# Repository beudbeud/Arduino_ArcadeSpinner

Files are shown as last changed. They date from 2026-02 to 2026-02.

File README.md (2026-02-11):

# Arduino Arcade Spinner

Ce projet est une recréation moderne des spinners utilisés dans les bornes d'arcade, principalement pour les casse-briques comme Arkanoid.

L'objectif est d'offrir une sensation proche de l'équipement d'origine en utilisant des composants faciles à obtenir.

Spinner
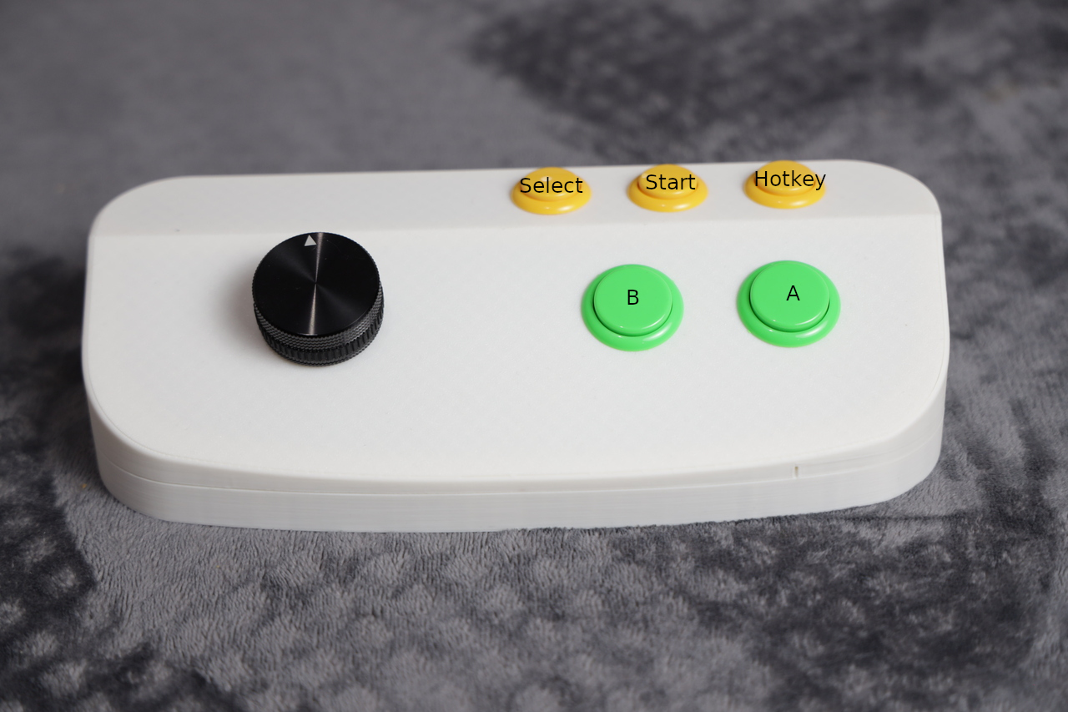
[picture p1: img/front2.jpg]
Spinner

Spinner

## Utilisation

Par défaut, l'appareil fonctionne comme un contrôleur à 5 boutons avec spinner, émulant une souris USB.

**Fonctionnalités :**
- Spinner haute précision (600 PPR par défaut)
- 5 boutons mappés sur les boutons de souris (gauche, droit, milieu, latéral, extra)
- 5 profiles de sensibilité ajustable via raccourcie
- Compatibilité universelle (Windows, Linux, MacOS, RetroPie, MiSTer, etc.)

### Changement de profile

Il y a 5 profiles:

 * Profile 0: Omega Race   - 64 PPR (Sega standard)
 * Profile 1: Tempest      - 72 PPR (Atari vector standard)
 * Profile 2: Tron/DoT     - 128 PPR
 * Profile 3: Blasteroids  - 288 PPR
 * Profile 4: Arkanoid     - 486 PPR (très sensible)

Par défaut au démarrage le spinner est configuré avec le profile 4. En jeux il est possible de changer le profile via le raccourci `Hotkey` + `B` pour diminer la sensibilité ou `Hotkey` + `A` pour augementer.

## Construire le vôtre

### Liste des composants

| Composant | Modèle recommandé | Quantité |
|---|---|---|
| Encodeur rotatif | C38S6G5-600B-G24N (600 PPR) | 1 |
| Microcontrôleur | Arduino | 1 |
| Boutons 24mm | Standard arcade | 3 |
| Boutons 30mm | Standard arcade | 2 |
| Boîtier | [Impression 3D](https://github.com/beudbeud/Arduino_ArcadeSpinner/tree/main/3D%20Files) ou boîte quelconque | 1 |
| Câbles | Dupont ou fils de connexion | - |

**Où acheter :**
- Encodeur rotatif : [AliExpress](https://fr.aliexpress.com/item/1005004359395872.html), Amazon (chercher "600PPR rotary encoder")
- Arduino Pro Micro : [AliExpress](https://fr.aliexpress.com/item/1005006734882677.html), [Amazon](https://www.amazon.fr/d%C3%A9veloppement-Binghe-Microcontr%C3%B4leurs-Interfaces-Compatible/dp/B0D69JLJ97), boutiques électronique
- Boutons arcade : [Boutiques spécialisées arcade](https://www.smallcab.net/boutons-c-30_35.html) ou AliExpress

### Schéma de câblage Arduino

Pinout Arduino

Les boutons doivent être connectés à la masse (GND). Vous pouvez créer une chaîne pour utiliser un GND commun pour tous vos boutons. Utilisez de la soudure ou des connecteurs de fils.

**⚠️ Important :** Faites le pont sur le pad J1 pour envoyer +5V à l'encodeur au lieu de 3.3V

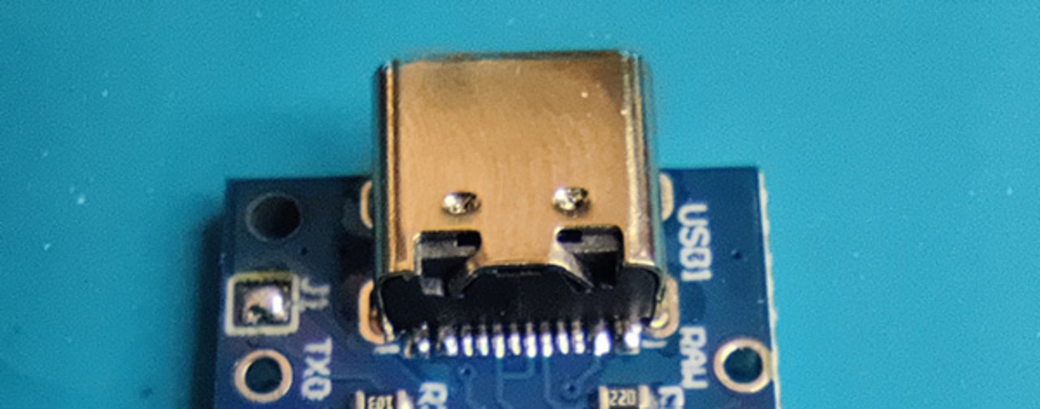
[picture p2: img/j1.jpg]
Pinout J1


#### Connexions détaillées

**Encodeur rotatif :**
```
Encodeur    →    Arduino Pro Micro
────────────────────────────────────
GND (fil noir)  →    GND
VCC (fil rouge) →    VCC (bridger J1 pour 5V)
A (fil blanc)   →    Pin 2 (GP_2)
B (fil vert)    →    Pin 3 (GP_3)
```
Pinout Rotary

**Boutons :**
```
Fonction          →    Pin Arduino    
─────────────────────────────────────
Button0 (B)      →    Pin 5 (GP_5)   
Button1 (A)      →    Pin 4 (GP_4)   
Button4 (Select) →    Pin 6 (GP_6)   
Button2 (Start)  →    Pin 14 (GP_14) 
Button3 (Hotkey) →    Pin 15 (GP_15) 
```
**Schéma de connexion des boutons :**
```
Relier toutes les masses → GND
```
Pinout Rotary

## Flasher votre Arduino

### Étape 1 : Installer Arduino IDE

1. Télécharger [Arduino IDE 2.x](https://www.arduino.cc/en/software)
2. Installer l'IDE sur votre ordinateur
3. Lancer Arduino IDE

### Étape 2 : Installer la bibliothèque HID-Project

1. Aller dans **Sketch** → **Include Library** → **Manage Libraries**
2. Rechercher "HID-Project"
3. Installer la bibliothèque

### Étape 3 : Configurer la carte

1. Connecter votre **Arduino Pro Micro** à l'ordinateur via USB
2. Dans Arduino IDE :
   - **Outils** → **Type de carte** → Sélectionner **Arduino Leonardo**
   - **Outils** → **Port** → Sélectionner le port COM correct

**Note :** L'Arduino Pro Micro utilise le même bootloader que le Leonardo.

### Étape 4 : Téléverser le code

1. Ouvrir le fichier `Arduino_ArcadeSpinner.ino`
2. Ajuster les paramètres de sensibilité si nécessaire (voir section Configuration)
3. Cliquer sur **Téléverser** (flèche →)
4. Attendre la compilation et le téléversement

## Options de personnalisation du code

Tous les paramètres ajustables se trouvent en haut du fichier `Arduino_ArcadeSpinner.ino` :

| Paramètre | Défaut | Description |
|---|---|---|
| `ENCODER_PPR` | 600 | PPR de votre encodeur (300, 360, 400, 600...) |
| `GAME_PPR[]` | 5 profils | Tableau des profils de sensibilité (modifiable/extensible) |
| `DEFAULT_PROFILE` | 4 | Profil au démarrage (index du tableau, 0 = premier) |
| `SENSITIVITY_MULTIPLIER` | 5 | Vitesse globale : 5 = précis, 10 = normal, 20 = rapide |
| `SCROLL_SENSITIVITY` | 400 | Sensibilité molette (↑ = moins sensible) |
| `RESPONSE_DELAY` | 1 | Délai en ms (1-2 recommandé) |
| `DEAD_ZONE` | 1 | Filtrage vibrations : 0 = off, 1-3 = recommandé |
| `LED_BLINK_TIME` | 80 | Durée clignotement LED (ms) |

### Profils de jeux (valeurs PPR arcade)

```
64  → Omega Race, Tac/Scan (Sega)    288 → Blasteroids
72  → Tempest, Super Sprint (Atari)  486 → Arkanoid, Puchi Carat
128 → Tron, Disks of Tron            144 → 720 Degrees
```

Pour ajouter un profil, ajoutez simplement une valeur au tableau `GAME_PPR[]`.

## Licence

Ce projet est sous licence GNU General Public License v3.0.

Basé sur les travaux de :
- Adrien Beudin ([beudbeud](https://github.com/beudbeud))
- Benoit BOUNAR (Bounitos) pour le boitier
- Alexey Melnikov ([MiSTer-devel](https://github.com/MiSTer-devel))
- Mikael Norrgård (mick@daemonbite.com)
- [willoucom](https://github.com/willoucom/Arduino_ArcadeSpinner)

## Contributions

Les contributions sont les bienvenues ! N'hésitez pas à :
- Ouvrir des issues pour signaler des bugs
- Proposer des améliorations via pull requests
- Partager vos builds et configurations

## Ressources supplémentaires

- [Documentation HID-Project](https://github.com/NicoHood/HID)
- [Arduino Pro Micro Guide](https://learn.sparkfun.com/tutorials/pro-micro--fio-v3-hookup-guide)
- [MAME Configuration Guide](https://docs.mamedev.org/)
- [Forum Arcade Controls](http://forum.arcadecontrols.com/)

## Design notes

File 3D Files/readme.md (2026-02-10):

# Arcade Spinner Case - 3D Model

[Français](#français) | [English](#english)

---

## 🇫🇷 Français

Ce dépôt contient les fichiers de conception numérique pour la coque du projet **Arduino Arcade Spinner**.

### 🔗 Projet Source
Ce modèle est optimisé pour le projet de spinner DIY :
👉 [Arduino Arcade Spinner sur GitHub](https://github.com/beudbeud/Arduino_ArcadeSpinner/tree/main)

### 👤 Auteur
- **Benoit BOUNAR** (Bounitos)

### 📁 Liste des fichiers (Nomenclature)
* **Panel.stl** : Panel principal.
* **Panel_Top_With_Logo.stl** : Panel supérieur avec emplacement logo.
* **Panel_Top_No_Logo.stl** : Panel supérieur (vierge).
* **Logo_Recalbox.stl** : Logo Recalbox à insérer.
* **Base.stl** : Partie inférieure (socle).
* **Arduino_Mount.stl** : Support de fixation interne pour l'Arduino.

### 📜 Conditions de Licence
Ce modèle numérique est mis à disposition sous licence **Creative Commons Attribution - Pas d'Utilisation Commerciale - Partage dans les Mêmes Conditions 4.0 International (CC BY-NC-SA 4.0)**.

**En utilisant ces fichiers, vous acceptez les clauses suivantes :**

* **Exploitation Non-Commerciale :** Toute exploitation commerciale de ce modèle, des fichiers sources ou des objets physiques issus de l'impression 3D est **strictement interdite**. Cela inclut la vente de kits, de coques pré-imprimées ou l'inclusion du design dans un produit payant.
* **Œuvres Dérivées :** La création d'œuvres dérivées (modifications, adaptations) est autorisée, à condition qu'elles soient distribuées sous une licence identique.
* **Obligation d'Attribution :** Toute redistribution ou exposition du modèle doit impérativement mentionner l'auteur original : **Benoit BOUNAR**, avec un lien vers le projet GitHub source.
* **Exclusion de Garantie :** Le modèle est fourni "en l'état", sans garantie de compatibilité matérielle ou de succès d'impression. L'auteur ne peut être tenu responsable des dommages liés à l'utilisation du modèle.

---

## 🇺🇸 English

This repository contains the digital design files for the **Arduino Arcade Spinner** housing.

### 🔗 Source Project
This model is designed for the following DIY Spinner project:
👉 [Arduino Arcade Spinner on GitHub](https://github.com/beudbeud/Arduino_ArcadeSpinner/tree/main)

### 👤 Author
- **Benoit BOUNAR** (Bounitos)

### 📁 File List (Nomenclature)
* **Panel.stl** : Main control panel.
* **Panel_Top_With_Logo.stl** : Upper panel with logo cutout.
* **Panel_Top_No_Logo.stl** : Upper panel (blank version).
* **Logo_Recalbox.stl** : Recalbox logo insert.
* **Base.stl** : Bottom base.
* **Arduino_Mount.stl** : Internal mounting bracket for the Arduino.

### 📜 Licensing Terms
This digital model is released under the **Creative Commons Attribution-NonCommercial-ShareAlike 4.0 International (CC BY-NC-SA 4.0)** license.

**By downloading or using these files, you agree to the following terms:**

* **Non-Commercial Restriction:** Any commercial exploitation of this model, its source files, or physical objects derived from 3D printing is **strictly prohibited**. This includes the sale of kits, pre-printed cases, or the inclusion of this design in a paid product.
* **Derivative Works:** You are permitted to remix or transform the material, provided that any derivative works are distributed under the same license as the original.
* **Mandatory Attribution:** Any redistribution or display of the model must include clear credit to the original author: **Benoit BOUNAR**, along with a link to the source GitHub repository.
* **Disclaimer of Warranty:** The model is provided "as is", without warranty of any kind. The author shall not be held liable for any damages resulting from the use or printing of this model.

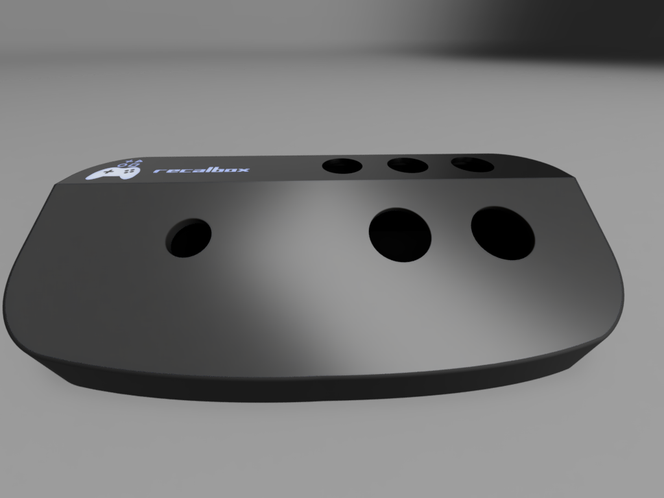
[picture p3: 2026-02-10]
3D Files/_Complete Case.png

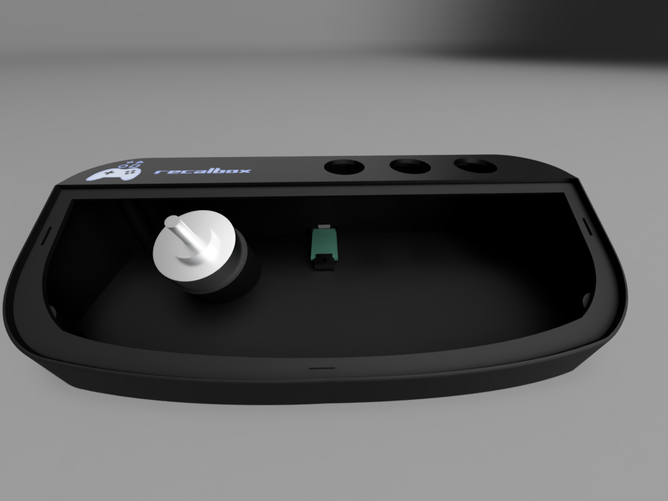
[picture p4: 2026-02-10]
3D Files/_Base + top case + Panel top.png

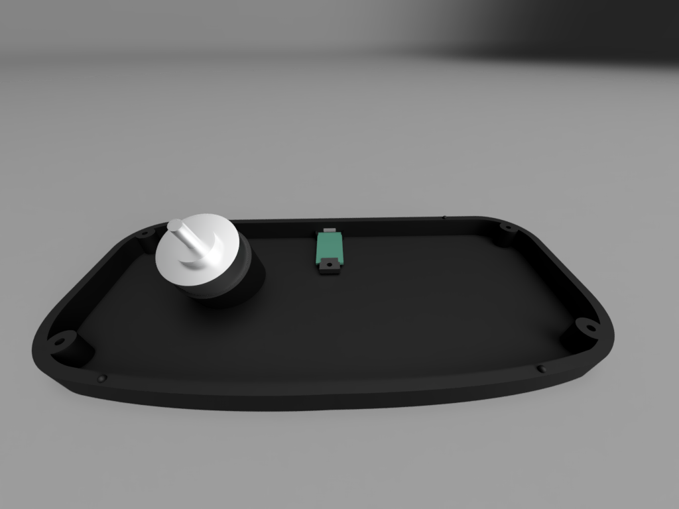
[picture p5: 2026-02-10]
3D Files/_base.png

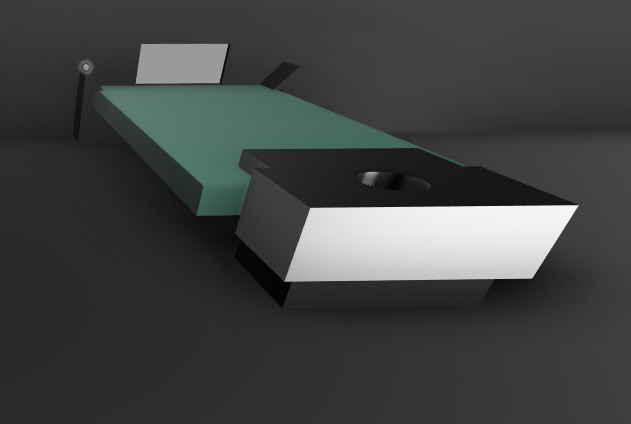
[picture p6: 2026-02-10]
3D Files/_Arduino Holder.png

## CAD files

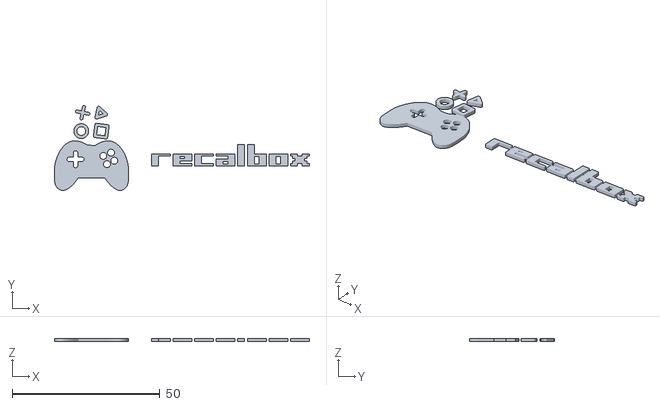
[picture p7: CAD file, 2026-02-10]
3D Files/STL files/Logo recalbox.stl
86.2 x 28.8 x 1.10

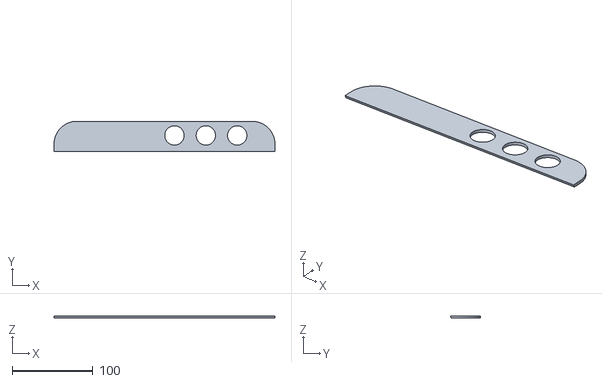
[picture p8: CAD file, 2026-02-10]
3D Files/STL files/Panel Top - without logo.stl
274.5 x 37.8 x 3.00

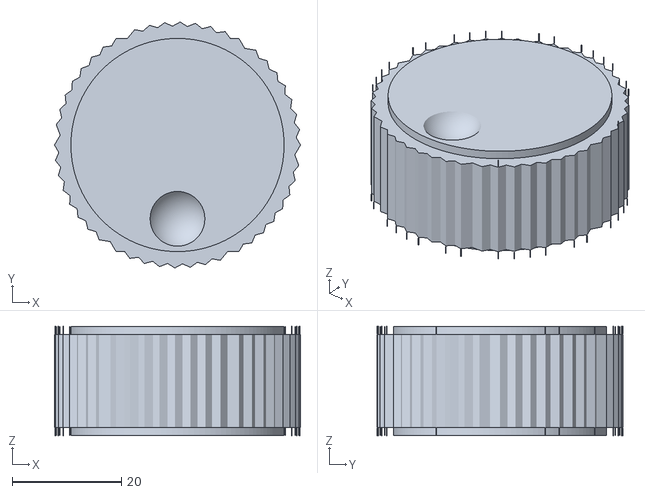
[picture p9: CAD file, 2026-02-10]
3D Files/STL files/Knob - Knob D-shape - D 42mm - H 20mm 3.stl
45.0 x 45.0 x 20.0

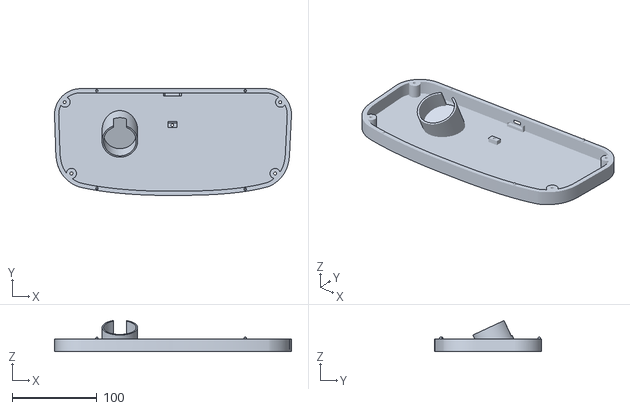
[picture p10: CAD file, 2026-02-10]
3D Files/STL files/Base.stl
279.3 x 125.8 x 36.5

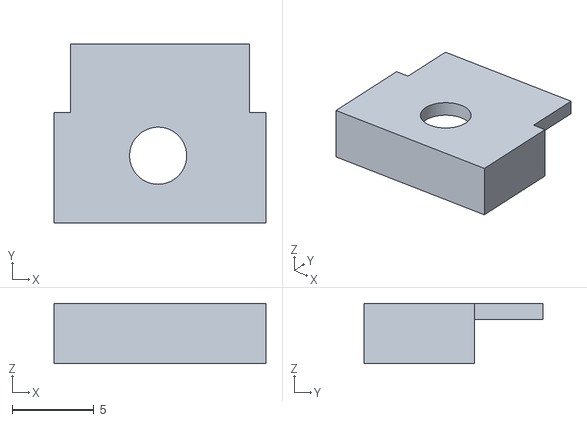
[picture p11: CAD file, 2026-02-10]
3D Files/STL files/Arduino Holder.stl
13.0 x 11.0 x 3.70

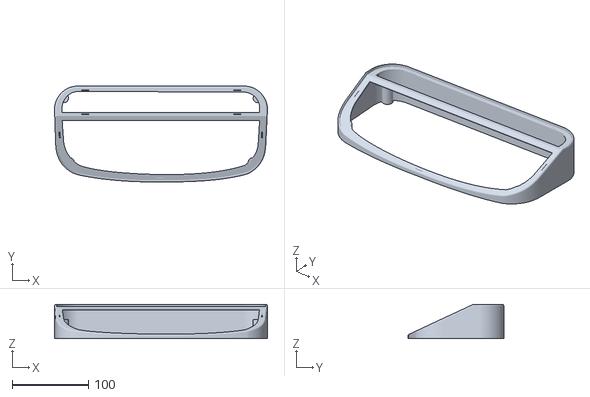
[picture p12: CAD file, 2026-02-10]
3D Files/STL files/Top_case.stl
279.3 x 125.8 x 45.0

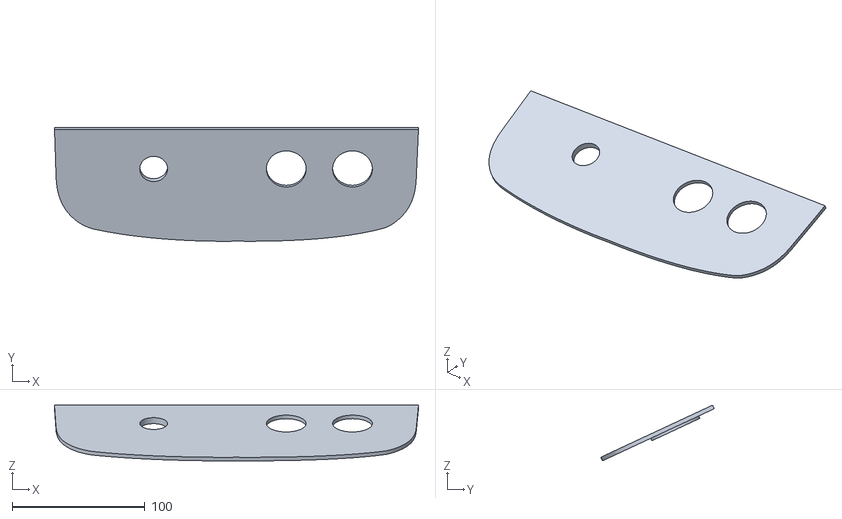
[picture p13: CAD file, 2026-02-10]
3D Files/STL files/Panel.stl
274.5 x 85.7 x 42.1

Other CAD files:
3D Files/STL files/Panel top - with logo.stl

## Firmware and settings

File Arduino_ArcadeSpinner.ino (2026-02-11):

/*
 *  Arduino USB Arcade Spinner
 *  (C) Adrien Beudin [https://github.com/beudbeud]
 *
 *  Based on project by Alexey Melnikov [https://github.com/MiSTer-devel/Retro-Controllers-USB-MiSTer/blob/master/PaddleTwoControllersUSB/PaddleTwoControllersUSB.ino]
 *  Based on project by Mikael Norrgård <mick@daemonbite.com>
 *  Based on project [https://github.com/willoucom/Arduino_ArcadeSpinner]
 *
 *  GNU GENERAL PUBLIC LICENSE
 *  Version 3, 29 June 2007
 *
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
 */

///////////////// Customizable settings /////////////////////////

// Your encoder's PPR (Pulses Per Revolution)
// Common values: 300, 360, 400, 600
// Quadrature encoding multiplies this by 4 (600 PPR = 2400 counts)
#define ENCODER_PPR 600
#define ENCODER_COUNTS (ENCODER_PPR * 4)  // 2400 for 600 PPR encoder

/*
 * Game Profiles - Based on original arcade hardware PPR
 *
 * Add, remove or modify profiles as needed!
 * Just update GAME_PPR array and NUM_PROFILES will auto-calculate.
 *
 * Common arcade game PPR values:
 *   64  - Omega Race, Tac/Scan, Zektor, Star Trek (Sega standard)
 *   72  - Tempest, Super Sprint (Atari vector standard)
 *   128 - Tron, Disks of Tron
 *   144 - 720 Degrees
 *   288 - Blasteroids
 *   486 - Arkanoid, Puchi Carat (geared, very sensitive)
 *
 * Sensitivity = ENCODER_COUNTS / GAME_PPR
 * Lower PPR value = less sensitive, Higher PPR value = more sensitive
 */

// ============== CUSTOMIZE YOUR PROFILES HERE ==============
const uint16_t GAME_PPR[] = {
  64,   // Profile 0: Omega Race / Sega
  72,   // Profile 1: Tempest / Atari
  128,  // Profile 2: Tron
  288,  // Profile 3: Blasteroids
  486   // Profile 4: Arkanoid / Puchi Carat
  // Add more profiles here, e.g.:
  // 144,  // Profile 5: 720 Degrees
  // 100,  // Profile 6: Custom
};
// ==========================================================

// Default profile index (0 = first profile in GAME_PPR array)
#define DEFAULT_PROFILE 4

// Sensitivity multiplier (adjusts speed on top of PPR profile)
// 5 = slower/more precise (0.5x), 10 = normal (1.0x), 20 = faster (2.0x)
// Using integer to avoid float operations in main loop
#define SENSITIVITY_MULTIPLIER 5

// Scroll wheel sensitivity (fixed, higher = less sensitive)
#define SCROLL_SENSITIVITY 400

// Response delay in ms (lower = more responsive, 1-2ms recommended)
#define RESPONSE_DELAY 1

// Dead zone - ignores small movements (noise/vibration filtering)
// 0 = disabled, 1-3 = recommended for filtering micro-movements
#define DEAD_ZONE 1

// LED feedback duration in ms
#define LED_BLINK_TIME 80

////////////////////// Don't Touche after that //////////////////

// Encoder pins
#define PIN_A 2
#define PIN_B 3

// Button pins
#define BTN_B      5   // Left button
#define BTN_A      4   // Right button
#define BTN_START  14  // Start button
#define BTN_HOTKEY 15  // Hotkey button
#define BTN_SELECT 6   // Select button

// Pro Micro onboard LEDs
#define LED_RX 17  // RX LED pin

#define SENSITIVITY_DIVISOR 10

// Auto-calculate number of profiles from array size
#define NUM_PROFILES (sizeof(GAME_PPR) / sizeof(GAME_PPR[0]))

#include <HID-Project.h>

// Mouse button definitions
#define MOUSE_SIDE  (1 << 3)
#define MOUSE_EXTRA (1 << 4)

// Spinner state
volatile int16_t spinnerPos = 0;

// Current profile
uint8_t currentProfile = DEFAULT_PROFILE;
uint16_t currentPPR = GAME_PPR[DEFAULT_PROFILE];

// Calculate sensitivity from PPR (inline function for efficiency)
inline uint8_t getSensitivity(uint16_t ppr) {  return ENCODER_COUNTS / ppr;
}

// Clamp value to int8 range
inline int8_t clamp8(int16_t val) {
  if (val > 127) return 127;
  if (val < -127) return -127;
  return val;
}

// Blink LEDs to indicate current profile
// Blinks (profile + 1) times: Profile 0 = 1 blink, Profile 4 = 5 blinks
void blinkProfile(uint8_t profile) {
  for (uint8_t i = 0; i <= profile; i++) {
    // Turn ON both LEDs (active LOW)
    digitalWrite(LED_RX, LOW);
    TXLED1;
    delay(LED_BLINK_TIME);

    // Turn OFF both LEDs
    digitalWrite(LED_RX, HIGH);
    TXLED0;
    delay(LED_BLINK_TIME);
  }
}

// Encoder interrupt handler (optimized with direct port reading)
void encoderISR() {
  static uint8_t prev = 0;

  // Direct port reading - much faster than digitalRead()
  // PIN_A = 2 = PD1, PIN_B = 3 = PD0 on Pro Micro
  uint8_t portD = PIND;
  uint8_t a = (portD >> 1) & 1;  // PD1 (pin 2)
  uint8_t b = portD & 1;          // PD0 (pin 3)

  uint8_t curr = (b << 1) | (b ^ a);
  int8_t diff = (prev - curr) & 3;

  if (diff == 1) spinnerPos++;
  else if (diff == 3) spinnerPos--;

  prev = curr;
}

void setup() {
  // Encoder pins
  pinMode(PIN_A, INPUT_PULLUP);
  pinMode(PIN_B, INPUT_PULLUP);

  // Button pins
  pinMode(BTN_A, INPUT_PULLUP);
  pinMode(BTN_B, INPUT_PULLUP);
  pinMode(BTN_START, INPUT_PULLUP);
  pinMode(BTN_HOTKEY, INPUT_PULLUP);
  pinMode(BTN_SELECT, INPUT_PULLUP);

  // LED pins
  pinMode(LED_RX, OUTPUT);
  digitalWrite(LED_RX, HIGH);  // OFF (active LOW)
  TXLED0;  // OFF

  // Attach encoder interrupts
  attachInterrupt(digitalPinToInterrupt(PIN_A), encoderISR, CHANGE);
  attachInterrupt(digitalPinToInterrupt(PIN_B), encoderISR, CHANGE);

  // Blink current profile on startup
  delay(500);
  blinkProfile(currentProfile);
}

void loop() {
  static bool prevBtnA = false;
  static bool prevBtnB = false;
  static int16_t prevMousePos = 0;
  static int16_t prevScrollPos = 0;

  // Read buttons
  bool hotkey = !digitalRead(BTN_HOTKEY);
  bool btnA = !digitalRead(BTN_A);
  bool btnB = !digitalRead(BTN_B);

  // Profile switching (Hotkey + A/B)
  // Hotkey + A = next profile (more sensitive)
  // Hotkey + B = previous profile (less sensitive)
  bool profileChanged = false;

  if (hotkey) {
    if (btnA && !prevBtnA && currentProfile < NUM_PROFILES - 1) {
      currentProfile++;
      currentPPR = GAME_PPR[currentProfile];
      profileChanged = true;
    }
    if (btnB && !prevBtnB && currentProfile > 0) {
      currentProfile--;
      currentPPR = GAME_PPR[currentProfile];
      profileChanged = true;
    }
  }
  prevBtnA = btnA;
  prevBtnB = btnB;

  const uint8_t buttons[] = {BTN_B, BTN_A, BTN_SELECT, BTN_START, BTN_HOTKEY};
  const uint8_t mouseButtons[] = {MOUSE_LEFT, MOUSE_RIGHT, MOUSE_SIDE, MOUSE_EXTRA, MOUSE_MIDDLE};

  // Blink LEDs if profile changed
  if (profileChanged) {
    blinkProfile(currentProfile);
  }

  for (uint8_t i = 0; i < 5; i++) {
    bool pressed = !digitalRead(buttons[i]);
    if (pressed && !Mouse.isPressed(mouseButtons[i])) {
      Mouse.press(mouseButtons[i]);
    } else if (!pressed && Mouse.isPressed(mouseButtons[i])) {
      Mouse.release(mouseButtons[i]);
    }
  }

  delay(RESPONSE_DELAY);

  // Calculate mouse and scroll movement (optimized integer math)
  int16_t pos = spinnerPos;  // Atomic read
  uint8_t currentSensitivity = getSensitivity(currentPPR);
  int16_t mousePos = (pos * SENSITIVITY_MULTIPLIER) / (currentSensitivity * SENSITIVITY_DIVISOR);
  int16_t scrollPos = pos / SCROLL_SENSITIVITY;

  int8_t mouseDelta = clamp8(mousePos - prevMousePos);
  int8_t scrollDelta = clamp8(scrollPos - prevScrollPos);

  // Apply dead zone - ignore small movements
  #if DEAD_ZONE > 0
    if (mouseDelta > -DEAD_ZONE && mouseDelta < DEAD_ZONE) mouseDelta = 0;
    if (scrollDelta > -DEAD_ZONE && scrollDelta < DEAD_ZONE) scrollDelta = 0;
  #endif

  prevMousePos += mouseDelta;
  prevScrollPos += scrollDelta;

  // Send mouse movement (horizontal + scroll inverted)
  Mouse.move(-mouseDelta, 0, scrollDelta);
}

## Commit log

2025-06-17 feat: make mouse with 5 buttons
    [ArcadeSpinner.stl, ArcadeSpinner_bottom.stl]
2025-06-17 fix: add 3rd hole for hotkey
    [ArcadeSpinner.stl, ArcadeSpinner_bottom.stl]
2025-06-19 fix: use SIDE and EXTRA btn
    [Arduino_ArcadeSpinner.ino]
2026-02-08 fix: name of button
    [Arduino_ArcadeSpinner.ino]
2026-02-08 fix: add arduino pic
2026-02-09 fix: pinA and pinB
    [Arduino_ArcadeSpinner.ino]
2026-02-10 fix: layout and ajout des fichier stl
    [ArcadeSpinner.stl, ArcadeSpinner_bottom.stl, Arduino Holder.stl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]
2026-02-10 fix: button order
2026-02-10 feat: blink led when changing profile

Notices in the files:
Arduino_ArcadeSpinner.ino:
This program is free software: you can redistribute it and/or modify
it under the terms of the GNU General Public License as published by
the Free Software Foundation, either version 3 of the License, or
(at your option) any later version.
